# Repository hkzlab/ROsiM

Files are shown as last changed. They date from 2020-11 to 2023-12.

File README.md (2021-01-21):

# ROsiM - ROM simulator

## Introduction

The ROsiM is a ROM simulation / emulation board: it uses two 512k/8bit SRAM chips to simulate an 8 or 16 bit ROM (up to 512k bytes or 512k words in size).

The board is based around an ATMega328P chip @20Mhz, controlled via serial connection.

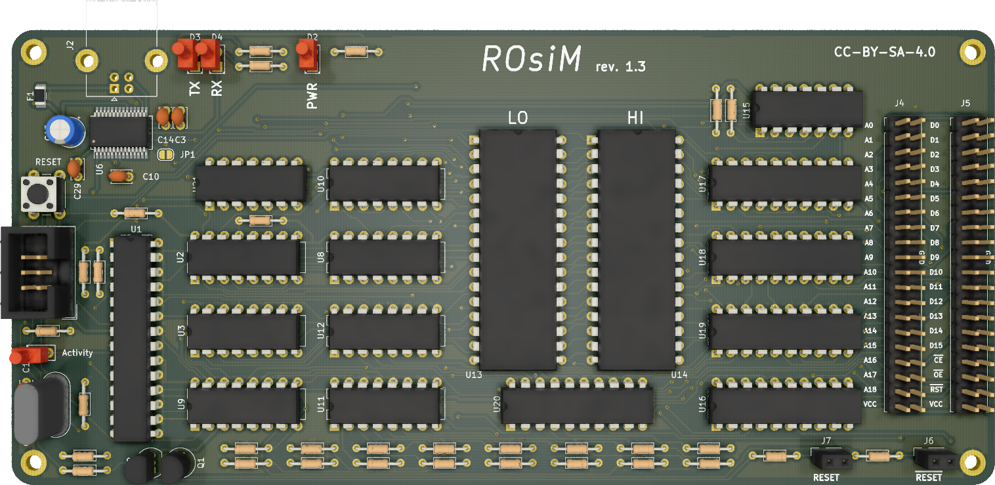
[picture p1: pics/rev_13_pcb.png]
Rev. 1.3 PCB


I made this out of my personal need of a simple way to quickly test ROM images on boards I repair/hack/build. Often, these boards use big 16bit EPROMs and the projects I found around did not cater to my needs.

The idea is to use this bare board and then "pods" that attach to the two 40pin header and adapt it to simulate various types of ROMs.

**WARNING:** While I might help you with quick questions, there is NOT going to be hand-holding for this one.

### Caveat Emptor!

I have currently built and tested revision 1.3 of this board. The following fixes must be implemented to make it usable:

- Wire the VCCIO pad from FT232RL to VCC and do NOT short it to 3.3v. This is already fixed in board rev. 1.4

The following mod is optional but encouraged for safety, and have been implemented for revision 1.4:

- Cut the trace between pin 1 of USB connector (Vcc) and F1, and insert a BAT48 SOD123 diode, cathode towards F1. This will protect your USB port if the board gets externally powered.
- Lower F1 max current to 200mA

## Board

This board is designed around relatively cheap through hole (with a few exceptions) components, and should be buildable by anyone with basic soldering skills.

You'll need a way to program your 328P MCU with the bootloader (you can then load the firmware via serial port).

I recommend [optiboot](https://github.com/Optiboot/optiboot). Remember to set the AVR frequency to 20Mhz and baudrate to 115200bps. I might provide prebuilt binaries of this in the future.

### Bill of Materials

**TODO**

### Connections

#### J1 - ISP 6 pin header

This is used for in-circuit programming of the MCU. You won't really use after burning the bootloader to the chip. You can leave this out if you pre-program the ATMega.

#### J2 - USB Type B female

Connect your USB cable here. It will appear as an FTDI serial port to the host.

The Interface runs at 230400bps 8-n-1. The protocol is mainly ASCII based, but meant to be used with an external software.

#### J3 - Barrel jack for power

Connect your DC power supply here, **center tip positive**.
Anything between 7 to 9V will be good, 12V will work, but the regulator might get hotter. 500mA should be enough.

#### J4 - Address header

A 40 pin header:

- Odd pins 1 thru 37 on the left side will bring out the address lines (A0-A18).
- Pin 39 will be this board's VCC.
- All even pins on the right are GND.

#### J5 - Data header

A 40 pin header: 

- Odd pins 1 thru 31 on the left side will bring out the data lines (D0-D15).
- Pin 33 will be the /CE signal input.
- Pin 35 will be the /OE signal input.
- Pin 39 will be this board's VCC.
- All even pins on the right are GND.

#### J6 - /RESET header

An active-low OC signal will be present on this header. You can use to pilot the /RESET of your target board.

Solder an arc of rigid wire on this one, so you can attach a small crocodile clip to it.

#### J7 - RESET header

An active-high signal (either high or disconnected) will be present on this header.

Solder an arc of rigid wire on this one, so you can attach a small crocodile clip to it.
## Software

While this board can be controlled directly via a simple serial terminal, it is advised to use a client software that supports the following protocol, like the [ROsiM Loader](https://github.com/hkzlab/ROsiM_Loader).

### Protocol

The **Remote Control** protocol is pretty simple and ASCII based. It supports 12 commands, each with its own syntax and response.

String `CMD_ERR` will be sent in case the command is not recognized, string `CMD_INV` will be sent in case the command cannot be executed at this time.

#### RESET

- Syntax: `>K<`
- Response: none

Forces the reset by watchdog of the ROsiM.

#### MODEL

- Syntax: `>M<`
- Response: `[M xx]`

Returns the current model of the board in hex. 

#### ADDRESS

- Syntax: `>A 00xxxxxx<`
- Response: `[A 00xxxxxx]`

Specifies the start address for the next read/write commands.
The address must be specified in hex, and a mask of 0x7FFFF will be applied to it.

#### WRITE

- Syntax: `>W xxxx<`
- Response: `[W xxxx]`

The SRAM must be in WRITE mode and the board switched to INTERNAL, otherwise the response `CMD_INV` will be sent.

`xxxx` is the data to write on SRAM at the current address in hex format.
Once the write completes, the **address will automatically increment by 1**.

#### READ

- Syntax: `>R<`
- Response: `[R xxxx]`

The SRAM must be in READ mode and the board switched to INTERNAL, otherwise the response `CMD_INV` will be sent.

`xxxx` is the data written at the current address in hex format. Once the read completes, the **address will automatically increment by 1**.

#### EXTERNAL RESET

- Syntax: `>E y<` where `y` can be `0` or `1`
- Response: `[E y]`

Enables (`1`) or disables (`0`) the external RESET signal to the target board.

#### INTERNAL/EXTERNAL SWITCH

- Syntax: `>S y<` where `y` can be `0` or `1`
- Response: `[S y]`

To execute this command, the SRAM must be in READ mode, otherwise the response `CMD_INV` will be sent.
Sets the board to INTERNAL (`1`) or EXTERNAL (`0`) mode. EXTERNAL mode will enable the drivers that communicate through the external address/data/control lines.

#### READ/WRITE SWITCH

- Syntax: `>X y<` where `y` can be `0` or `1`
- Response: `[X y]`

To execute this command, the board must be in INTERNAL mode, otherwise the response `CMD_INV` will be sent.
Sets the SRAM to READ (`1`) or WRITE (`0`) mode.

#### VIEW

- Syntax: `>V<`
- Response: `[V 00xxxxxx yy]`

This command will print out the current address in hex format (`00xxxxxx`) and a mask (`yy`) in hex format that contains:

- bit 0: INTERNAL/EXTERNAL state
- bit 1: READ/WRITE state
- bit 2: EXTERNAL RESET state

#### DEFAULTS

- Syntax: `>D<`
- Response: `[D]`

Will revert the board state to the following state:

- INTERNAL
- SRAM in READ mode
- EXTERNAL RESET disabled

The selection of the EXTERNAL RESET logic will **NOT** be restored by this command and will remain set to the current state.

#### TEST

- Syntax: `>T<`
- Response: `[T xx]`

Resets the board to defaults then executes a test on the SRAMs by writing patterns of data in them and reading them back.

The output can be:

- `00` test was completed successfully
- `01` test failed while writing the first pattern (`0xAA55`)
- `02` test failed while writing the first pattern (`0x55AA`)
- `03` the test failed while writing the incremental pattern

#### XMODEM

- Syntax: `>O x<`
- Response: `[O yy]`

Starts an XMODEM transfer of a binary file into the SRAM.

`x` can be:

- `0` The file will be considered an 8-bit dump, the highest 8 bits of the SRAM will be set to `0x00`, only the lower 8 bits will be set.
- `1` The file will be considered a 16-bit dump, and the data will be loaded into the SRAM in words. ODD bytes in the dump will end up in the high byte of the SRAM, EVEN bytes will end up in the low byte of the SRAM.
- `2` The file will be considered a **byte swapped** 16-bit dump, and the data will be loaded into the SRAM in words. EVEN bytes in the dump will end up in the high byte of the SRAM, ODD bytes will end up in the low byte of the SRAM.

`yy` will be:

- `00` for a failed transfer.
- `01` for a successful transfer.

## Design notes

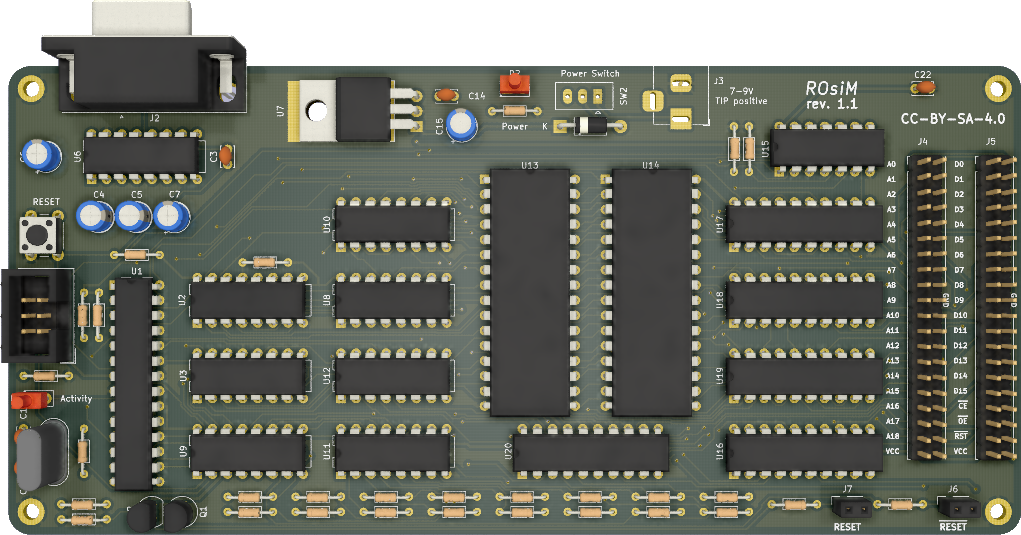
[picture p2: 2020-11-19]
pics/rev_11_pcb.png

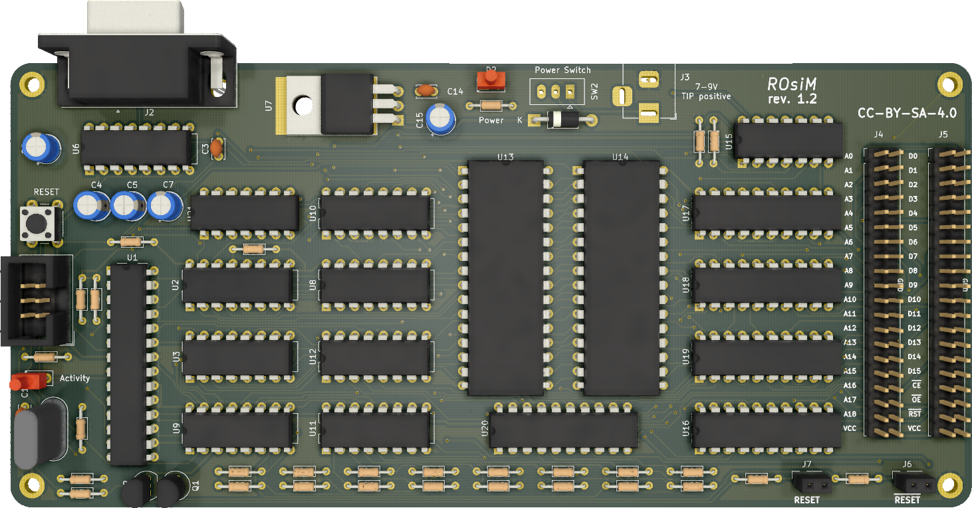
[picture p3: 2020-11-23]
pics/rev_12_pcb.png

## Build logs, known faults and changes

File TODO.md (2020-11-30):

## Use 1mbyte SRAMs

See if 1Mbyte SRAMs are available and use them for new designs.

## Use SPI for 'HC595

Use SPI to load HC595 registers instead of bit-banging them.

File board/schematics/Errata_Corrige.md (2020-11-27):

# Errata Corrige

## Version 1.1 - 1.3

- The MCU is actually an ATMega328P, not an ATMega8
- The crystal is a 20Mhz crystal, not 8Mhz

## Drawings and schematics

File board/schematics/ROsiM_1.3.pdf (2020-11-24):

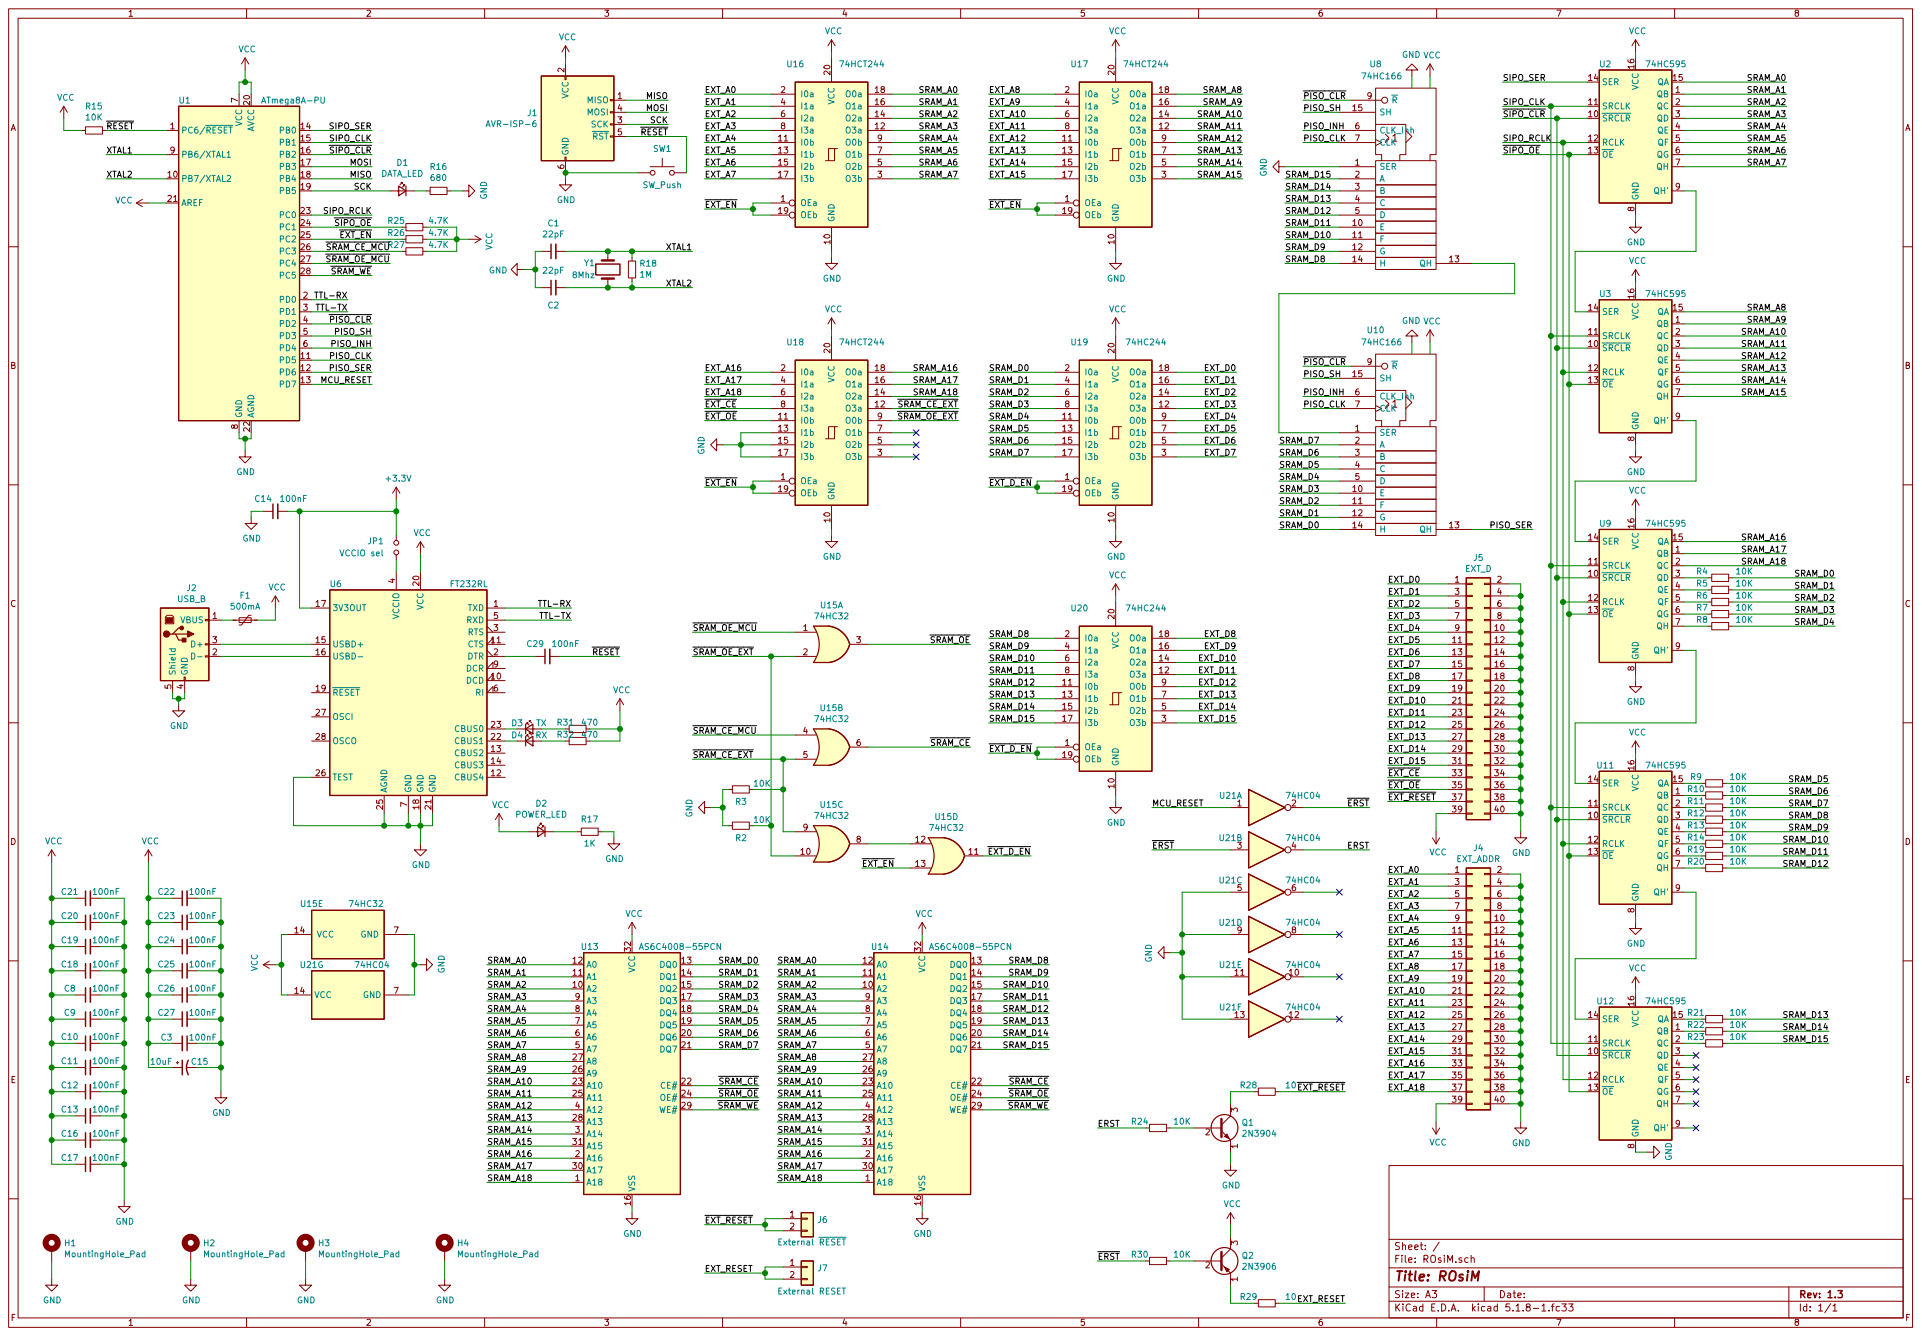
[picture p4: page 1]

2 SCK 3 MOSI 4 RST 5 GND

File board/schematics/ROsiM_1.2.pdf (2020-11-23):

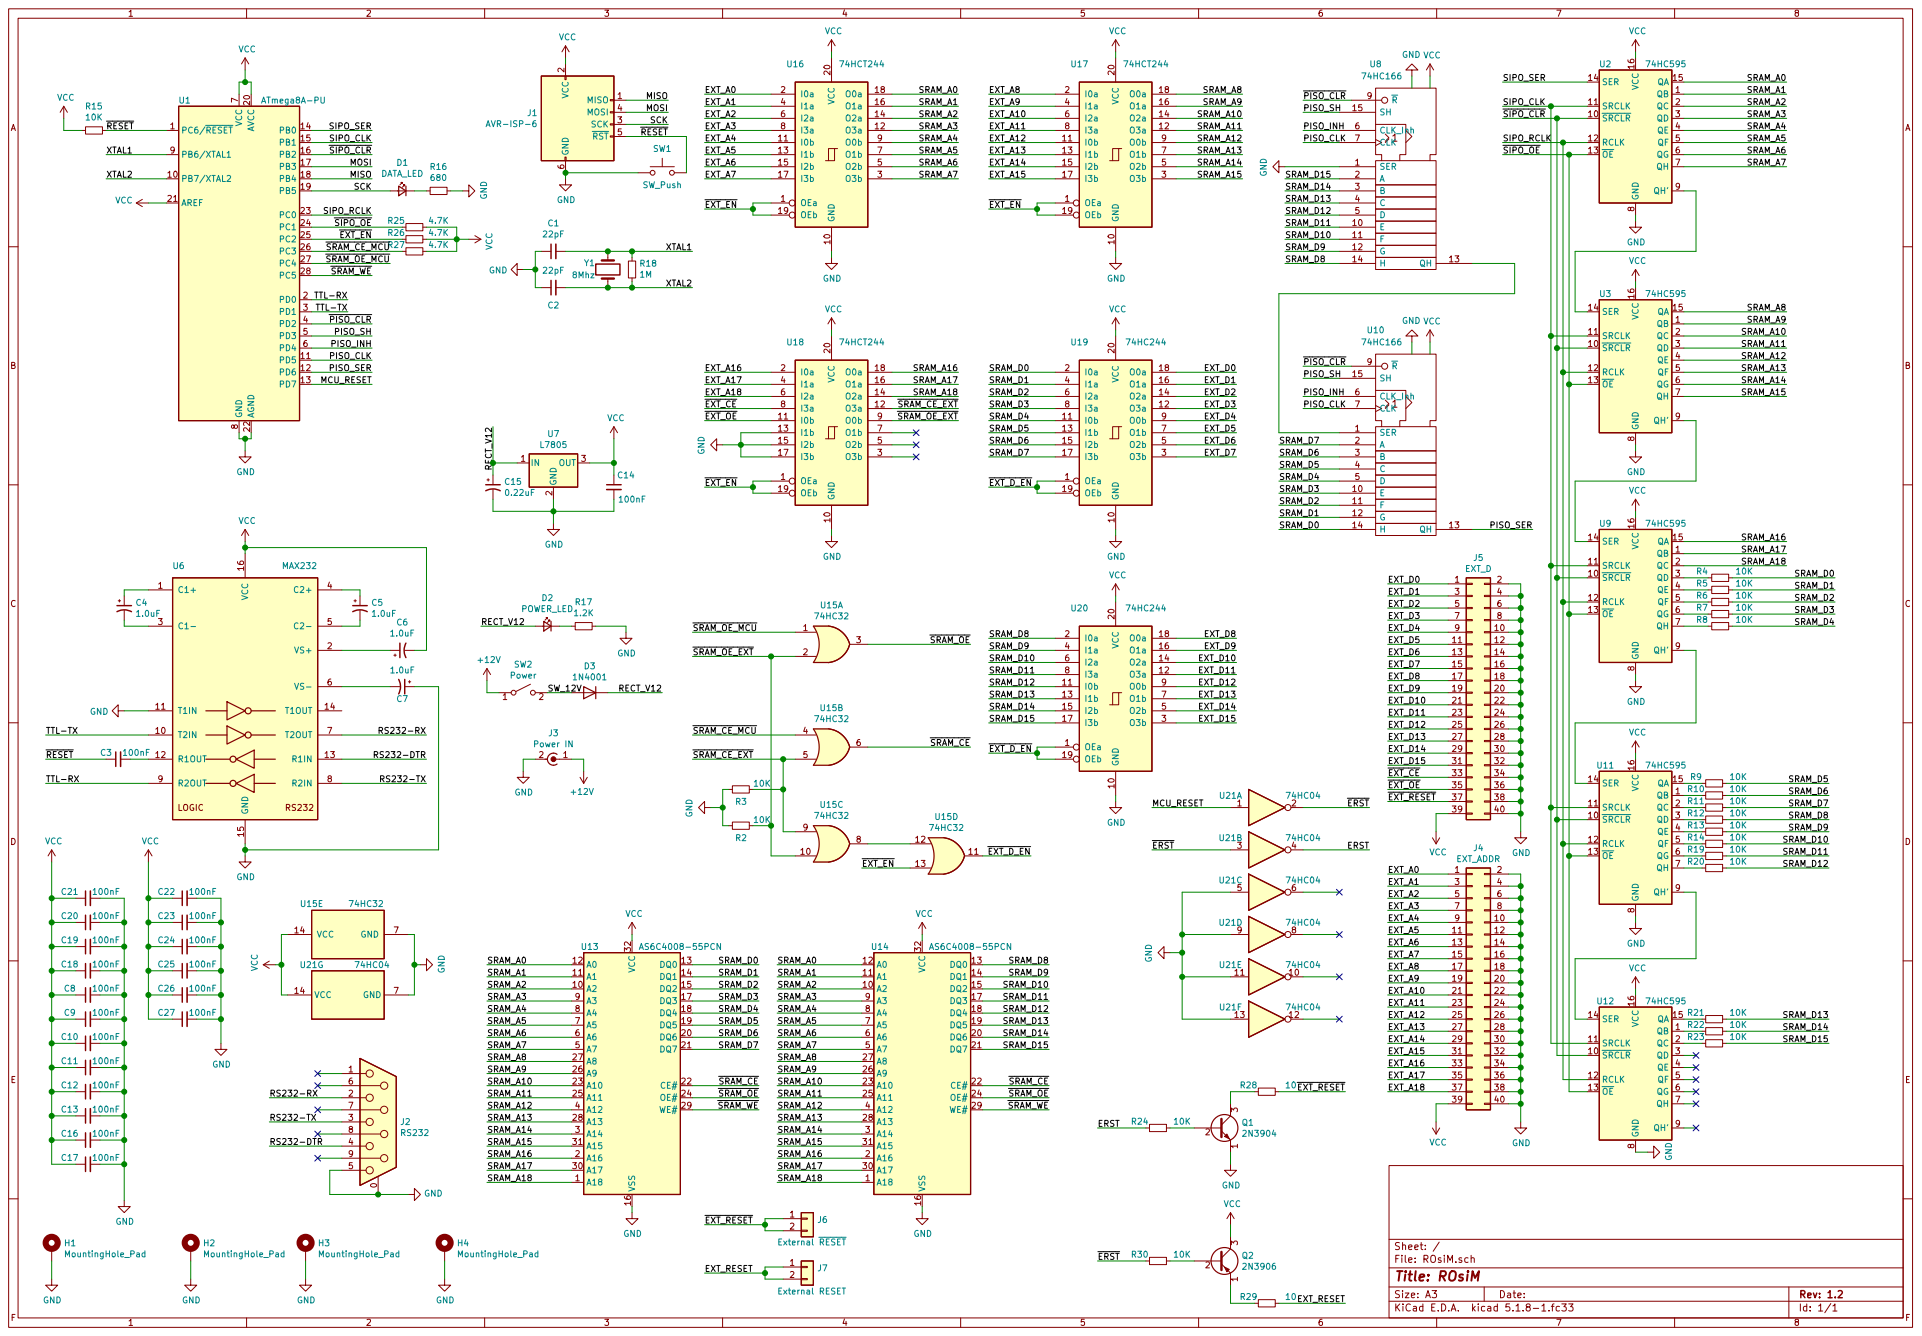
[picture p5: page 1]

2 SCK 3 MOSI 4 RST 5 GND

File: ROsiM.sch Sheet: /
Id: 1/1 Title: ROsiM

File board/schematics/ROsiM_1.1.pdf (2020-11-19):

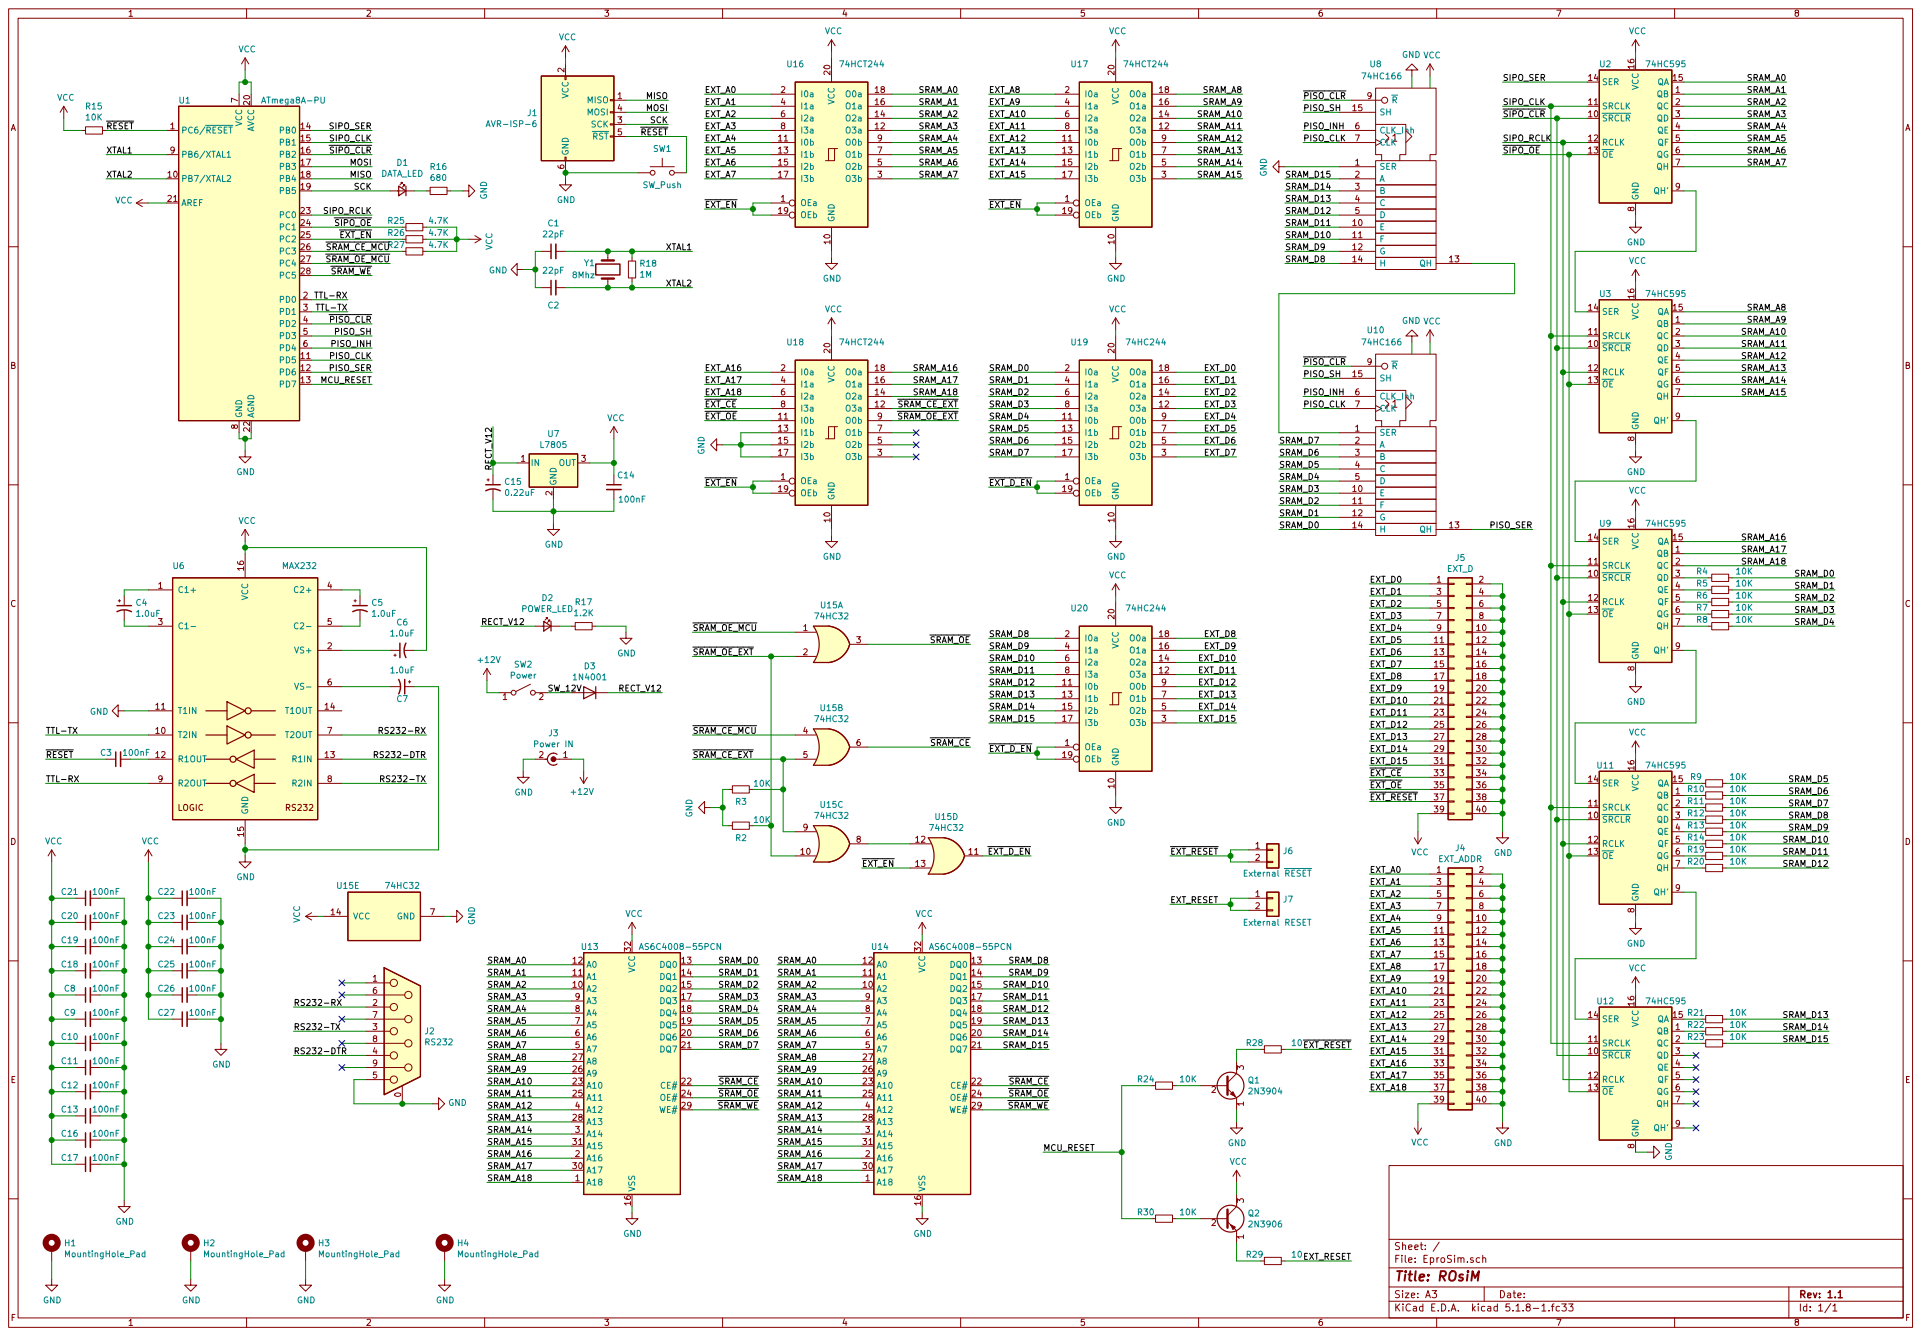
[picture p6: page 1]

2 SCK 3 MOSI 4 RST 5 GND

RESET SCK MOSI MISO

8 QH' 9 U9 74HC595 VCC GND GND

8 QH' 9 U12 74HC595 GND GND GND GND

File: EproSim.sch Sheet: /
Id: 1/1 Title: ROsiM

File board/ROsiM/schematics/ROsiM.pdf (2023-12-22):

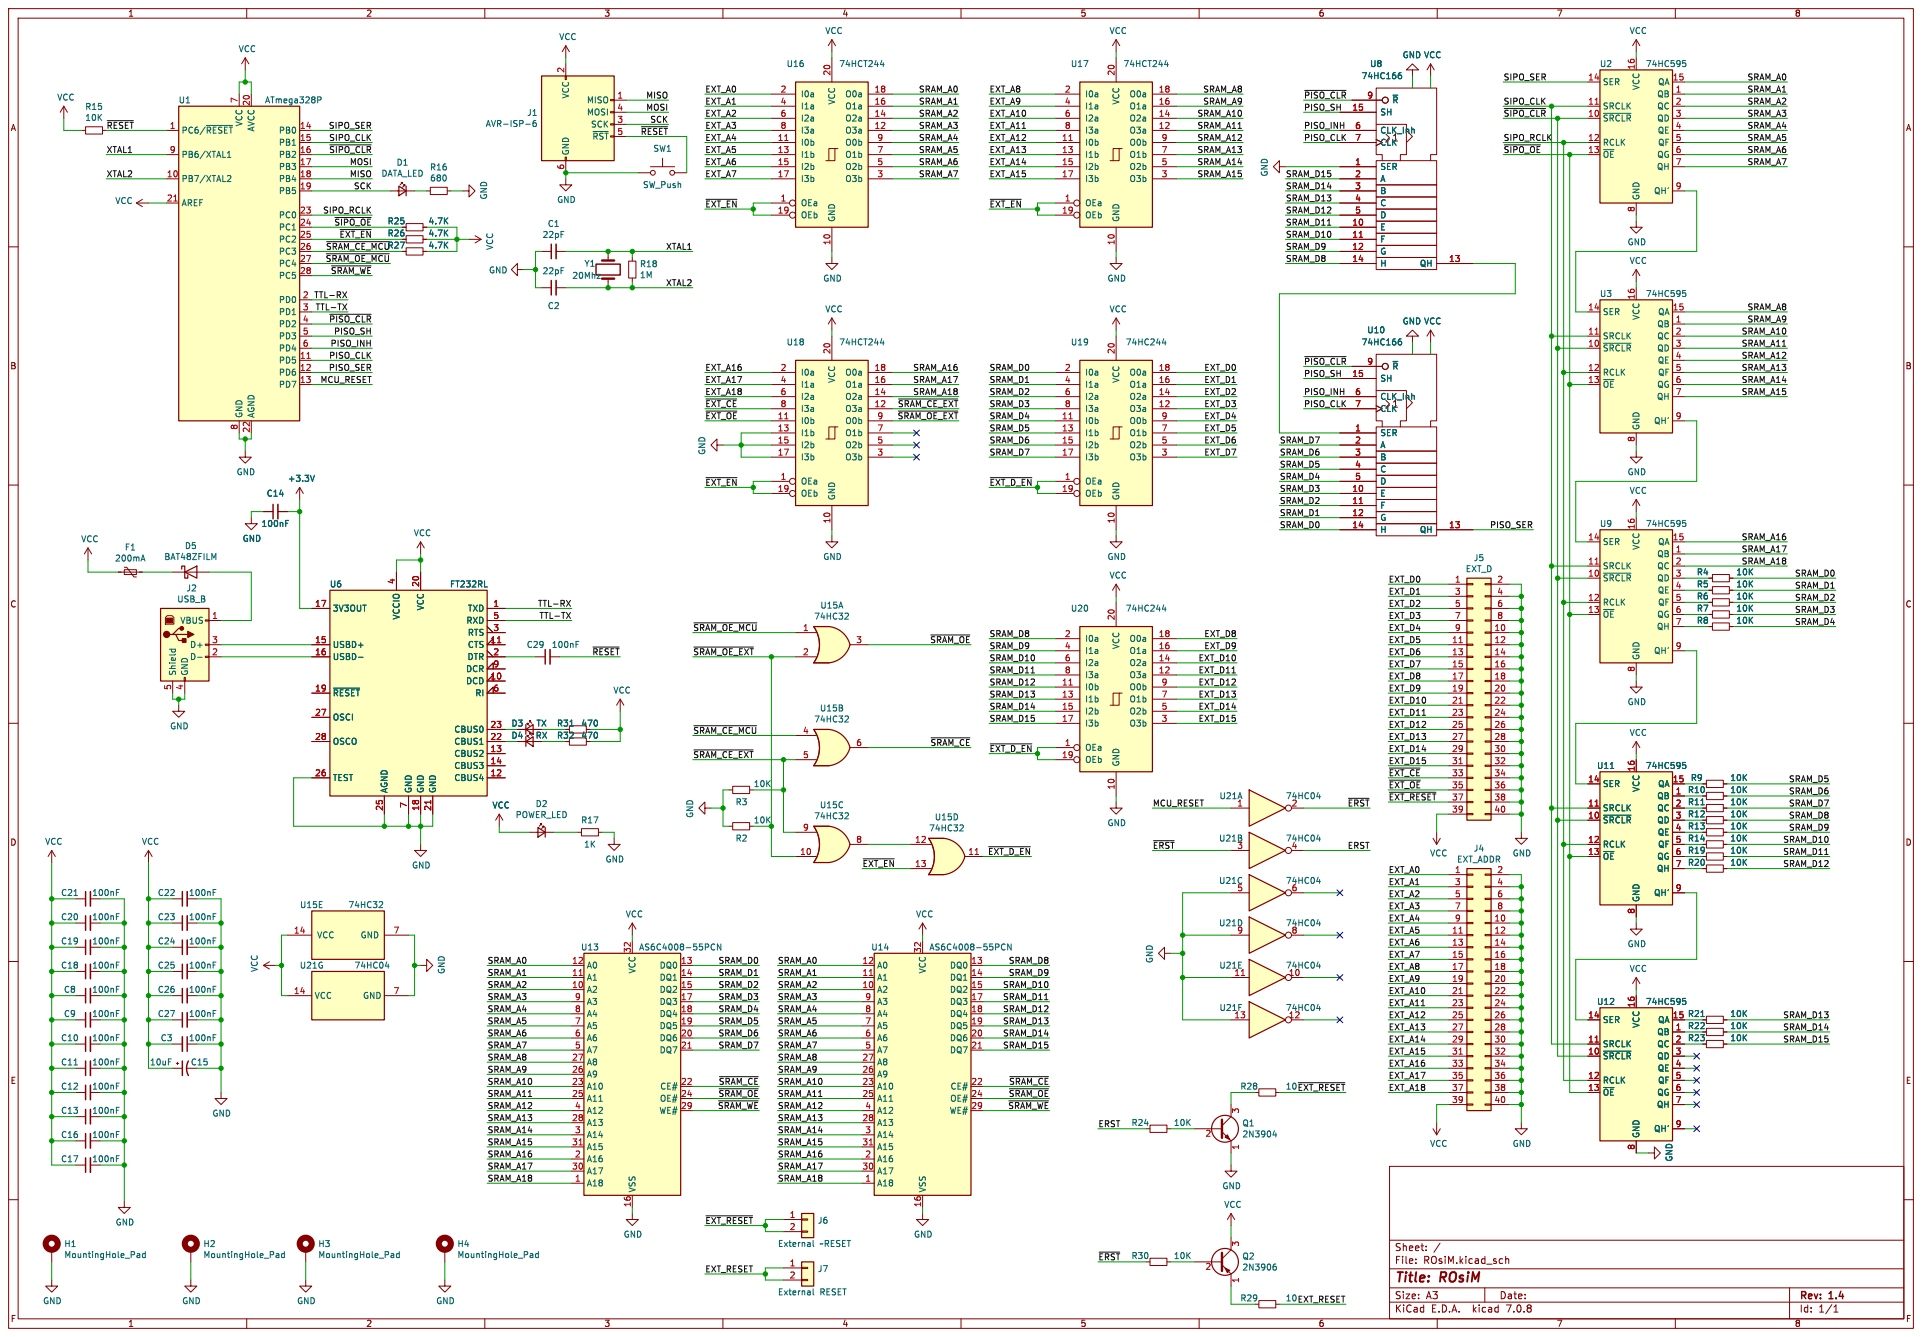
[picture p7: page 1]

7 DCR 9 GND VCC GND VCC

2 SCK 3 MOSI 4 ~{RST}5 GND
MISO VCC

SRAM_A3 MOSI SCK MOSI MISO

TXD 1 DCD 10 CTS 11 CBUS4 12 CBUS2 13 CBUS3 14 USBD+ 15 USBD- 16

7 DCR 9 U6 FT232RL VSS 16 VCC 32 A18 1 A2 10 A1 11 A0 12 DQ0 13 DQ1 14 DQ2 15 DQ3 17 DQ4 18 DQ5 19 A16 2 DQ6 20 DQ7 21 CE# 22 A10 23 OE# 24 A11 25 A9 26 A8 27 A13 28 WE# 29 A14 3 A17 30 A15 31 A12 4 A7 5 A6 6 A5 7 A4 8 A3 9 U13 AS6C4008-55PCN

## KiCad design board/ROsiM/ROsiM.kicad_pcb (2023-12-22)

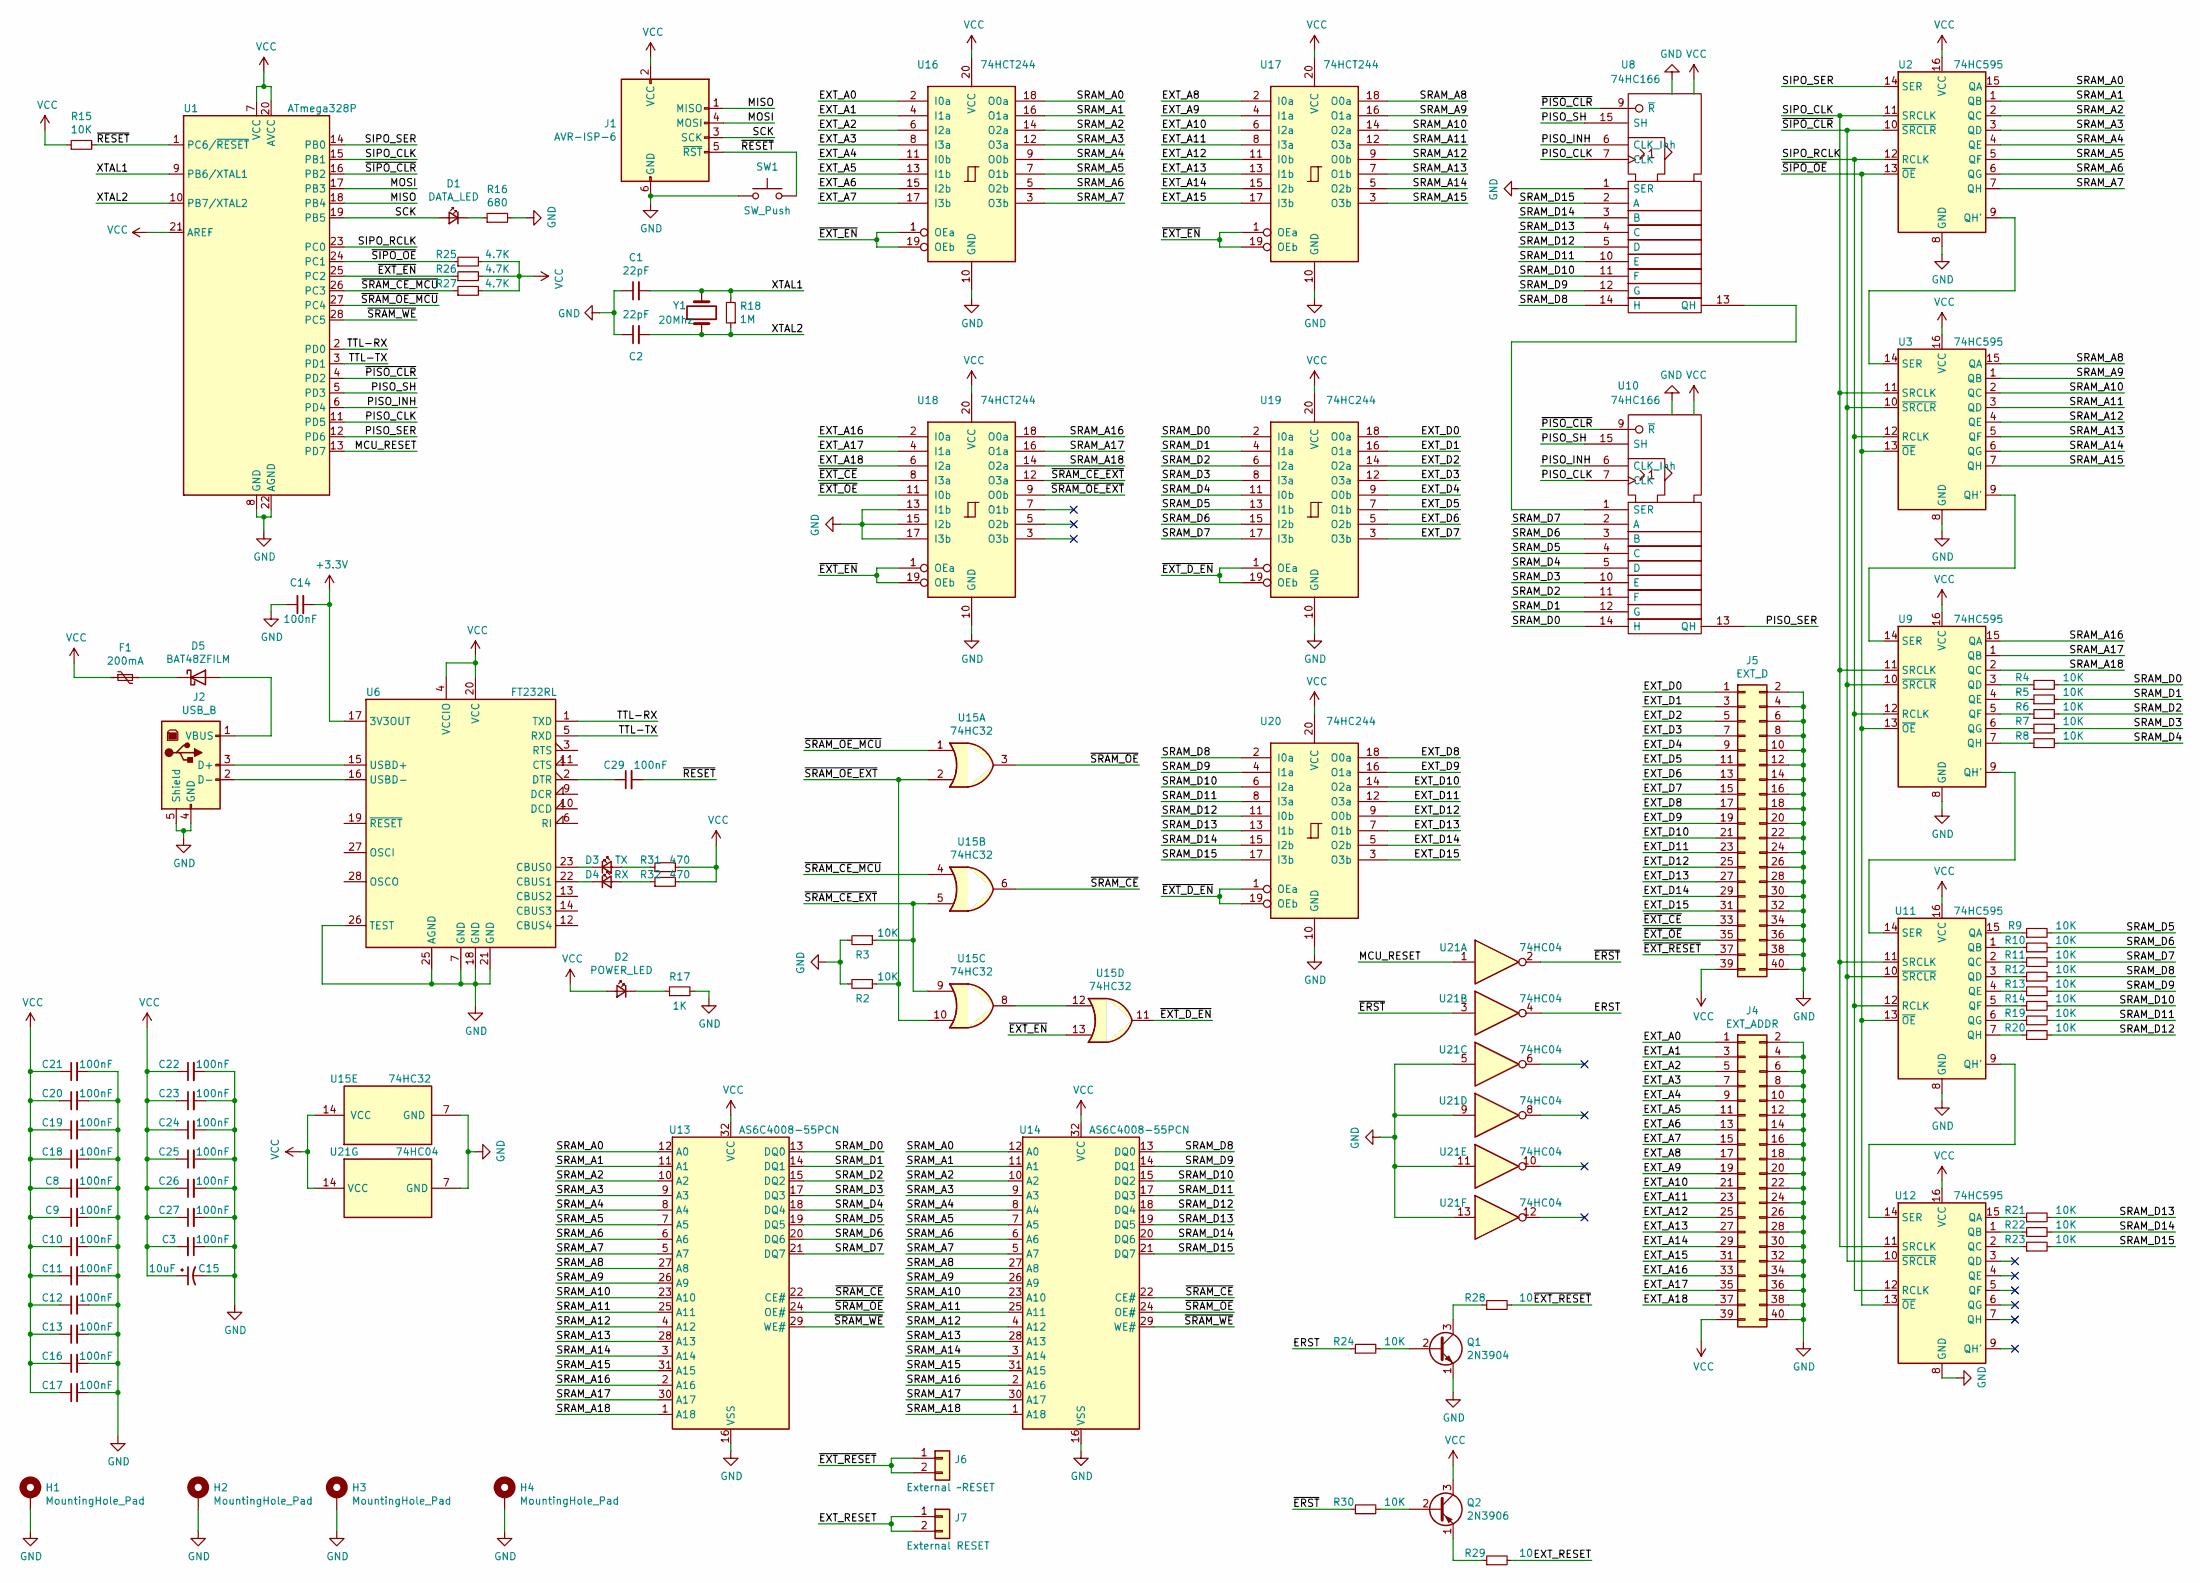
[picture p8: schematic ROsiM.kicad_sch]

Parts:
C1, C2: 22pF; C_Disc_D3.0mm_W2.0mm_P2.50mm
C3, C8, C9, C10, C11, C12, C13, C14, C16, C17, C18, C19, C20, C21, C22, C23, C24, C25, C26, C27, C29: 100nF; C_Disc_D3.4mm_W2.1mm_P2.50mm
C15: 10uF; CP_Radial_D5.0mm_P2.50mm
D1: DATA_LED; LED_D2.0mm_W4.8mm_H2.5mm_FlatTop
D2: POWER_LED; LED_D2.0mm_W4.8mm_H2.5mm_FlatTop
D3: TX; LED_D2.0mm_W4.8mm_H2.5mm_FlatTop
D4: RX; LED_D2.0mm_W4.8mm_H2.5mm_FlatTop
D5: BAT48ZFILM; D_SOD-123
F1: 200mA; Fuse_1206_3216Metric
H1, H2, H3, H4: MountingHole_Pad; MountingHole_2.7mm_M2.5_ISO7380_Pad
J1: AVR-ISP-6; IDC-Header_2x03_P2.54mm_Vertical
J2: USB_B; USB_B_Lumberg_2411_02_Horizontal
J4: EXT_ADDR; PinHeader_2x20_P2.54mm_Vertical
J5: EXT_D; PinHeader_2x20_P2.54mm_Vertical
J6: External ~RESET; PinSocket_1x02_P2.54mm_Vertical
J7: External RESET; PinSocket_1x02_P2.54mm_Vertical
Q1: 2N3904; TO-92_Inline
Q2: 2N3906; TO-92_Inline
R2, R3, R4, R5, R6, R7, R8, R9, R10, R11, R12, R13, R14, R15, R19, R20, R21, R22, R23, R24, R30: 10K; R_Axial_DIN0204_L3.6mm_D1.6mm_P7.62mm_Horizontal
R16: 680; R_Axial_DIN0204_L3.6mm_D1.6mm_P7.62mm_Horizontal
R17: 1K; R_Axial_DIN0204_L3.6mm_D1.6mm_P7.62mm_Horizontal
R18: 1M; R_Axial_DIN0204_L3.6mm_D1.6mm_P7.62mm_Horizontal
R25, R26, R27: 4.7K; R_Axial_DIN0204_L3.6mm_D1.6mm_P7.62mm_Horizontal
R28, R29: 10; R_Axial_DIN0204_L3.6mm_D1.6mm_P7.62mm_Horizontal
R31, R32: 470; R_Axial_DIN0204_L3.6mm_D1.6mm_P7.62mm_Horizontal
SW1: SW_Push; SW_PUSH_6mm
U1: ATmega328P; DIP-28_W7.62mm
U2, U3, U9, U11, U12: 74HC595; DIP-16_W7.62mm
U6: FT232RL; SSOP-28_5.3x10.2mm_P0.65mm
U8, U10: 74HC166; DIP-16_W7.62mm
U13, U14: AS6C4008-55PCN; DIP-32_W15.24mm
U15: 74HC32; DIP-14_W7.62mm
U16, U17, U18: 74HCT244; DIP-20_W7.62mm
U19, U20: 74HC244; DIP-20_W7.62mm
U21: 74HC04; DIP-14_W7.62mm
Y1: 20Mhz; Crystal_HC49-U_Vertical

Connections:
+3V3: C14.2, U6.17 (3V3OUT)
/ERST: R24.1, U21.4
/EXT_A0: J4.1, U16.2 (I0a)
/EXT_A1: J4.3, U16.4 (I1a)
/EXT_A2: J4.5, U16.6 (I2a)
/EXT_A3: J4.7, U16.8 (I3a)
/EXT_A4: J4.9, U16.11 (I0b)
/EXT_A5: J4.11, U16.13 (I1b)
/EXT_A6: J4.13, U16.15 (I2b)
/EXT_A7: J4.15, U16.17 (I3b)
/EXT_A8: J4.17, U17.2 (I0a)
/EXT_A9: J4.19, U17.4 (I1a)
/EXT_A10: J4.21, U17.6 (I2a)
/EXT_A11: J4.23, U17.8 (I3a)
/EXT_A12: J4.25, U17.11 (I0b)
/EXT_A13: J4.27, U17.13 (I1b)
/EXT_A14: J4.29, U17.15 (I2b)
/EXT_A15: J4.31, U17.17 (I3b)
/EXT_A16: J4.33, U18.2 (I0a)
/EXT_A17: J4.35, U18.4 (I1a)
/EXT_A18: J4.37, U18.6 (I2a)
/EXT_D0: J5.1, U19.18 (O0a)
/EXT_D1: J5.3, U19.16 (O1a)
/EXT_D2: J5.5, U19.14 (O2a)
/EXT_D3: J5.7, U19.12 (O3a)
/EXT_D4: J5.9, U19.9 (O0b)
/EXT_D5: J5.11, U19.7 (O1b)
/EXT_D6: J5.13, U19.5 (O2b)
/EXT_D7: J5.15, U19.3 (O3b)
/EXT_D8: J5.17, U20.18 (O0a)
/EXT_D9: J5.19, U20.16 (O1a)
/EXT_D10: J5.21, U20.14 (O2a)
/EXT_D11: J5.23, U20.12 (O3a)
/EXT_D12: J5.25, U20.9 (O0b)
/EXT_D13: J5.27, U20.7 (O1b)
/EXT_D14: J5.29, U20.5 (O2b)
/EXT_D15: J5.31, U20.3 (O3b)
/EXT_RESET: J7.1, J7.2, R29.2
/MCU_RESET: U1.13 (PD7), U21.1
/MISO: J1.1 (MISO), U1.18 (PB4)
/MOSI: J1.4 (MOSI), U1.17 (PB3)
/PISO_CLK: U1.11 (PD5), U8.7 (CLK), U10.7 (CLK)
/PISO_INH: U1.6 (PD4), U8.6 (CLK_Inh), U10.6 (CLK_Inh)
/PISO_SER: U1.12 (PD6), U10.13 (QH)
/PISO_SH: U1.5 (PD3), U8.15 (SH), U10.15 (SH)
/SCK: D1.2 (A), J1.3 (SCK), U1.19 (PB5)
/SIPO_CLK: U1.15 (PB1), U2.11 (SRCLK), U3.11 (SRCLK), U9.11 (SRCLK), U11.11 (SRCLK), U12.11 (SRCLK)
/SIPO_RCLK: U1.23 (PC0), U2.12 (RCLK), U3.12 (RCLK), U9.12 (RCLK), U11.12 (RCLK), U12.12 (RCLK)
/SIPO_SER: U1.14 (PB0), U2.14 (SER)
/SRAM_A0: U2.15 (QA), U13.12 (A0), U14.12 (A0), U16.18 (O0a)
/SRAM_A1: U2.1 (QB), U13.11 (A1), U14.11 (A1), U16.16 (O1a)
/SRAM_A2: U2.2 (QC), U13.10 (A2), U14.10 (A2), U16.14 (O2a)
/SRAM_A3: U2.3 (QD), U13.9 (A3), U14.9 (A3), U16.12 (O3a)
/SRAM_A4: U2.4 (QE), U13.8 (A4), U14.8 (A4), U16.9 (O0b)
/SRAM_A5: U2.5 (QF), U13.7 (A5), U14.7 (A5), U16.7 (O1b)
/SRAM_A6: U2.6 (QG), U13.6 (A6), U14.6 (A6), U16.5 (O2b)
/SRAM_A7: U2.7 (QH), U13.5 (A7), U14.5 (A7), U16.3 (O3b)
/SRAM_A8: U3.15 (QA), U13.27 (A8), U14.27 (A8), U17.18 (O0a)
/SRAM_A9: U3.1 (QB), U13.26 (A9), U14.26 (A9), U17.16 (O1a)
/SRAM_A10: U3.2 (QC), U13.23 (A10), U14.23 (A10), U17.14 (O2a)
/SRAM_A11: U3.3 (QD), U13.25 (A11), U14.25 (A11), U17.12 (O3a)
/SRAM_A12: U3.4 (QE), U13.4 (A12), U14.4 (A12), U17.9 (O0b)
/SRAM_A13: U3.5 (QF), U13.28 (A13), U14.28 (A13), U17.7 (O1b)
/SRAM_A14: U3.6 (QG), U13.3 (A14), U14.3 (A14), U17.5 (O2b)
/SRAM_A15: U3.7 (QH), U13.31 (A15), U14.31 (A15), U17.3 (O3b)
/SRAM_A16: U9.15 (QA), U13.2 (A16), U14.2 (A16), U18.18 (O0a)
/SRAM_A17: U9.1 (QB), U13.30 (A17), U14.30 (A17), U18.16 (O1a)
/SRAM_A18: U9.2 (QC), U13.1 (A18), U14.1 (A18), U18.14 (O2a)
/SRAM_D0: R4.2, U10.14 (H), U13.13 (DQ0), U19.2 (I0a)
/SRAM_D1: R5.2, U10.12 (G), U13.14 (DQ1), U19.4 (I1a)
/SRAM_D2: R6.2, U10.11 (F), U13.15 (DQ2), U19.6 (I2a)
/SRAM_D3: R7.2, U10.10 (E), U13.17 (DQ3), U19.8 (I3a)
/SRAM_D4: R8.2, U10.5 (D), U13.18 (DQ4), U19.11 (I0b)
/SRAM_D5: R9.2, U10.4 (C), U13.19 (DQ5), U19.13 (I1b)
/SRAM_D6: R10.2, U10.3 (B), U13.20 (DQ6), U19.15 (I2b)
/SRAM_D7: R11.2, U10.2 (A), U13.21 (DQ7), U19.17 (I3b)
/SRAM_D8: R12.2, U8.14 (H), U14.13 (DQ0), U20.2 (I0a)
/SRAM_D9: R13.2, U8.12 (G), U14.14 (DQ1), U20.4 (I1a)
/SRAM_D10: R14.2, U8.11 (F), U14.15 (DQ2), U20.6 (I2a)
/SRAM_D11: R19.2, U8.10 (E), U14.17 (DQ3), U20.8 (I3a)
/SRAM_D12: R20.2, U8.5 (D), U14.18 (DQ4), U20.11 (I0b)
/SRAM_D13: R21.2, U8.4 (C), U14.19 (DQ5), U20.13 (I1b)
/SRAM_D14: R22.2, U8.3 (B), U14.20 (DQ6), U20.15 (I2b)
/SRAM_D15: R23.2, U8.2 (A), U14.21 (DQ7), U20.17 (I3b)
/TTL-RX: U1.2 (PD0), U6.1 (TXD)
/TTL-TX: U1.3 (PD1), U6.5 (RXD)
/XTAL1: C1.2, R18.2, U1.9 (PB6/XTAL1), Y1.2
/XTAL2: C2.2, R18.1, U1.10 (PB7/XTAL2), Y1.1
/~ERST: R30.1, U21.2, U21.3
/~EXT_CE: J5.33, U18.8 (I3a)
/~EXT_D_EN: U15.11, U19.1 (OEa), U19.19 (OEb), U20.1 (OEa), U20.19 (OEb)
/~EXT_EN: R26.1, U1.25 (PC2), U15.13, U16.1 (OEa), U16.19 (OEb), U17.1 (OEa), U17.19 (OEb), U18.1 (OEa), U18.19 (OEb)
/~EXT_OE: J5.35, U18.11 (I0b)
/~EXT_RESET: J5.37, J6.1, J6.2, R28.2
/~PISO_CLR: U1.4 (PD2), U8.9 (~R), U10.9 (~R)
/~RESET: C29.2, J1.5 (~RST), R15.2, SW1.2, U1.1 (PC6/~RESET)
/~SIPO_CLR: U1.16 (PB2), U2.10 (~SRCLR), U3.10 (~SRCLR), U9.10 (~SRCLR), U11.10 (~SRCLR), U12.10 (~SRCLR)
/~SIPO_OE: R25.1, U1.24 (PC1), U2.13 (~OE), U3.13 (~OE), U9.13 (~OE), U11.13 (~OE), U12.13 (~OE)
/~SRAM_CE_EXT: R3.1, U15.5, U15.9, U18.12 (O3a)
/~SRAM_CE_MCU: R27.1, U1.26 (PC3), U15.4
/~SRAM_CE: U13.22 (CE#), U14.22 (CE#), U15.6
/~SRAM_OE_EXT: R2.1, U15.2, U15.10, U18.9 (O0b)
/~SRAM_OE_MCU: U1.27 (PC4), U15.1
/~SRAM_OE: U13.24 (OE#), U14.24 (OE#), U15.3
/~SRAM_WE: U1.28 (PC5), U13.29 (WE#), U14.29 (WE#)
GND: C1.1, C2.1, C3.1, C8.2, C9.2, C10.2, C11.2, C12.2, C13.2, C14.1, C15.2, C16.2, C17.2, C18.2, C19.2, C20.2, C21.2, C22.2, C23.2, C24.2, C25.2, C26.2, C27.2, H1.1, H2.1, H3.1, H4.1, J1.6 (GND), J2.4 (GND), J2.5 (Shield), J4.2, J4.4, J4.6, J4.8, J4.10, J4.12, J4.14, J4.16, J4.18, J4.20, J4.22, J4.24, J4.26, J4.28, J4.30, J4.32, J4.34, J4.36, J4.38, J4.40, J5.2, J5.4, J5.6, J5.8, J5.10, J5.12, J5.14, J5.16, J5.18, J5.20, J5.22, J5.24, J5.26, J5.28, J5.30, J5.32, J5.34, J5.36, J5.38, J5.40, Q1.1 (E), R2.2, R3.2, R16.2, R17.2, SW1.1, U1.8 (GND), U1.22 (AGND), U2.8 (GND), U3.8 (GND), U6.7 (GND), U6.18 (GND), U6.21 (GND), U6.25 (AGND), U6.26 (TEST), U8.1 (SER), U8.8 (GND), U9.8 (GND), U10.8 (GND), U11.8 (GND), U12.8 (GND), U13.16 (VSS), U14.16 (VSS), U15.7 (GND), U16.10 (GND), U17.10 (GND), U18.10 (GND), U18.13 (I1b), U18.15 (I2b), U18.17 (I3b), U19.10 (GND), U20.10 (GND), U21.5, U21.7 (GND), U21.9, U21.11, U21.13
unnamed: C29.1, U6.2 (DTR)
unnamed: D1.1 (K), R16.1
unnamed: D2.1 (K), R17.1
unnamed: D3.1 (K), U6.23 (CBUS0)
unnamed: D3.2 (A), R31.1
unnamed: D4.1 (K), U6.22 (CBUS1)
unnamed: D4.2 (A), R32.1
unnamed: D5.1 (K), F1.2
unnamed: D5.2 (A), J2.1 (VBUS)
unnamed: J2.2 (D-), U6.16 (USBD-)
unnamed: J2.3 (D+), U6.15 (USBD+)
unnamed: Q1.2 (B), R24.2
unnamed: Q1.3 (C), R28.1
unnamed: Q2.1 (E), R29.1
unnamed: Q2.2 (B), R30.2
unnamed: R4.1, U9.3 (QD)
unnamed: R5.1, U9.4 (QE)
unnamed: R6.1, U9.5 (QF)
unnamed: R7.1, U9.6 (QG)
unnamed: R8.1, U9.7 (QH)
unnamed: R9.1, U11.15 (QA)
unnamed: R10.1, U11.1 (QB)
unnamed: R11.1, U11.2 (QC)
unnamed: R12.1, U11.3 (QD)
unnamed: R13.1, U11.4 (QE)
unnamed: R14.1, U11.5 (QF)
unnamed: R19.1, U11.6 (QG)
unnamed: R20.1, U11.7 (QH)
unnamed: R21.1, U12.15 (QA)
unnamed: R22.1, U12.1 (QB)
unnamed: R23.1, U12.2 (QC)
unnamed: U2.9 (QH'), U3.14 (SER)
unnamed: U3.9 (QH'), U9.14 (SER)
unnamed: U8.13 (QH), U10.1 (SER)
unnamed: U11.9 (QH'), U12.14 (SER)
unnamed: U9.9 (QH'), U11.14 (SER)
unnamed: U15.8, U15.12
VCC: C3.2, C8.1, C9.1, C10.1, C11.1, C12.1, C13.1, C15.1, C16.1, C17.1, C18.1, C19.1, C20.1, C21.1, C22.1, C23.1, C24.1, C25.1, C26.1, C27.1, D2.2 (A), F1.1, J1.2 (VCC), J4.39, J5.39, Q2.3 (C), R15.1, R25.2, R26.2, R27.2, R31.2, R32.2, U1.7 (VCC), U1.20 (AVCC), U1.21 (AREF), U2.16 (VCC), U3.16 (VCC), U6.4 (VCCIO), U6.20 (VCC), U8.16 (VCC), U9.16 (VCC), U10.16 (VCC), U11.16 (VCC), U12.16 (VCC), U13.32 (VCC), U14.32 (VCC), U15.14 (VCC), U16.20 (VCC), U17.20 (VCC), U18.20 (VCC), U19.20 (VCC), U20.20 (VCC), U21.14 (VCC)

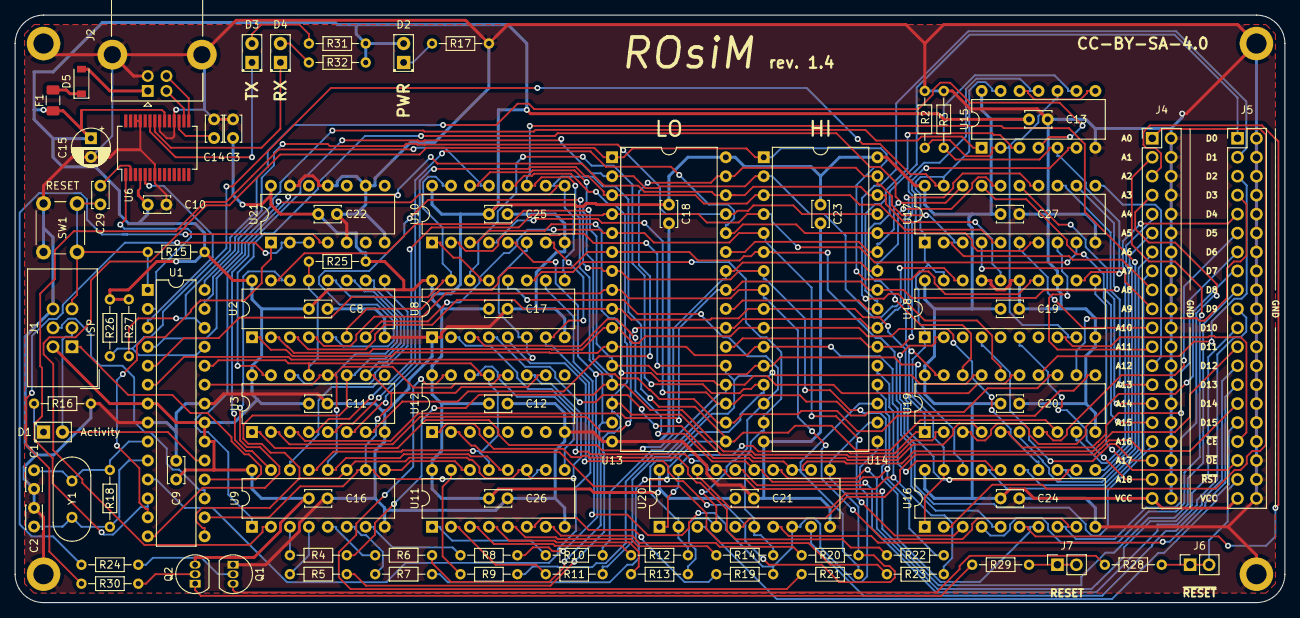
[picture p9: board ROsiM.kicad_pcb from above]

Board: 2 copper layers, 170.2 x 78.7 mm, 93 parts (0 on the bottom side), 144 nets.

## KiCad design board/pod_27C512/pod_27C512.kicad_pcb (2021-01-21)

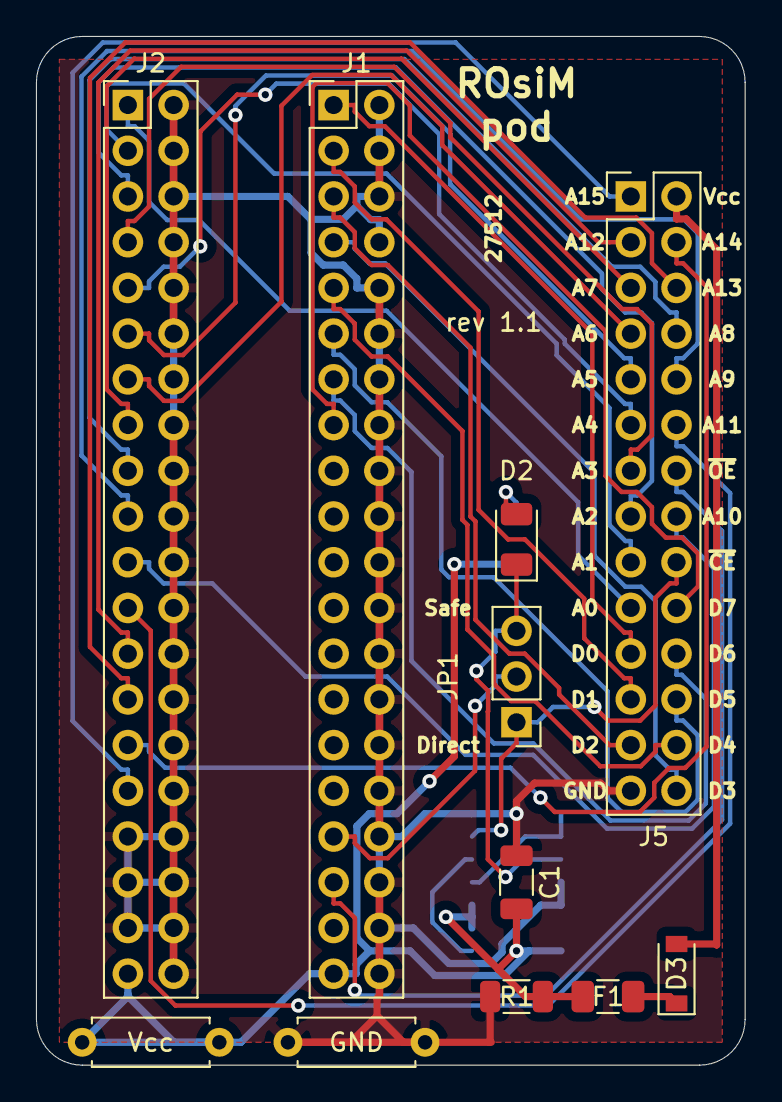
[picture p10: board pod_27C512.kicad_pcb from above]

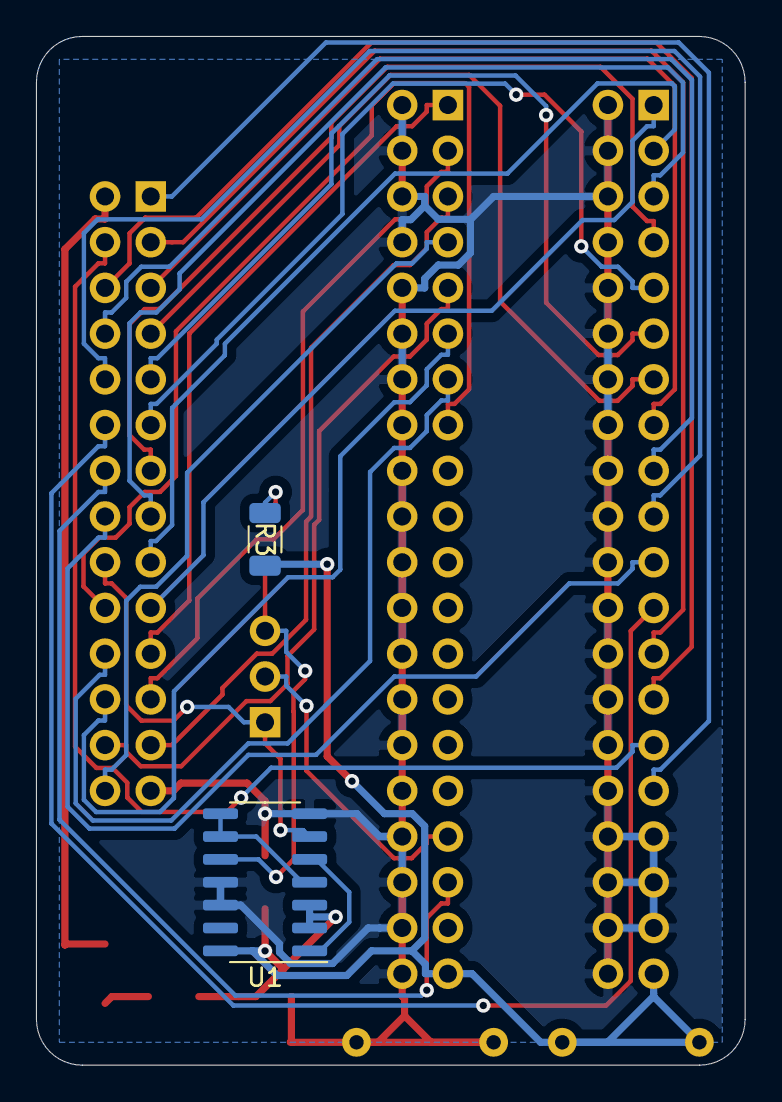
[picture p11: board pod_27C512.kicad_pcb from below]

Board: 2 copper layers, 39.4 x 57.2 mm, 13 parts (2 on the bottom side), 35 nets.

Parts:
C1: 100nF; C_1206_3216Metric
D2: GREEN; LED_1206_3216Metric
D3: BAT48ZFILM; D_SOD-123
F1: 200mA; Fuse_1206_3216Metric
J1: EXT_D; PinHeader_2x20_P2.54mm_Vertical
J2: EXT_ADDR; PinHeader_2x20_P2.54mm_Vertical
J3: VCC_Probe; R_Axial_DIN0207_L6.3mm_D2.5mm_P7.62mm_Horizontal
J4: GND_Probe; R_Axial_DIN0207_L6.3mm_D2.5mm_P7.62mm_Horizontal
J5: ROM Lines; PinHeader_2x14_P2.54mm_Vertical
JP1: /OE Selection; PinHeader_1x03_P2.54mm_Vertical
R1: 4.7K; R_1206_3216Metric
R3: 470; R_1206_3216Metric
U1: 74HCT02; SO-14_3.9x8.65mm_P1.27mm

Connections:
/A0: J2.1, J5.19
/A1: J2.3, J5.17
/A2: J2.5, J5.15
/A3: J2.7, J5.13
/A4: J2.9, J5.11
/A5: J2.11, J5.9
/A6: J2.13, J5.7
/A7: J2.15, J5.5
/A8: J2.17, J5.8
/A9: J2.19, J5.10
/A10: J2.21, J5.16
/A11: J2.23, J5.12
/A12: J2.25, J5.3
/A13: J2.27, J5.6
/A14: J2.29, J5.4
/A15: J2.31, J5.1
/D0: J1.1, J5.21
/D1: J1.3, J5.23
/D2: J1.5, J5.25
/D3: J1.7, J5.28
/D4: J1.9, J5.26
/D5: J1.11, J5.24
/D6: J1.13, J5.22
/D7: J1.15, J5.20
/~B_CE: J1.33, JP1.2
/~DIR_CE: J5.18, JP1.1, U1.6
/~OE: J1.35, J5.14
/~SAFE_CE: D2.1, JP1.3, U1.10
GND: C1.1, J1.2, J1.4, J1.6, J1.8, J1.10, J1.12, J1.14, J1.16, J1.18, J1.20, J1.22, J1.24, J1.26, J1.28, J1.30, J1.32, J1.34, J1.36, J1.38, J1.40, J2.2, J2.4, J2.6, J2.8, J2.10, J2.12, J2.14, J2.16, J2.18, J2.20, J2.22, J2.24, J2.26, J2.28, J2.30, J2.32, J2.33, J2.34, J2.35, J2.36, J2.37, J2.38, J2.40, J4.1, J4.2, J5.27, R1.1, U1.7, U1.11, U1.12
unnamed: D2.2, R3.1
unnamed: D3.1, F1.1
unnamed: D3.2, J5.2
unnamed: U1.1, U1.5
unnamed: U1.4, U1.8, U1.9
VCC: C1.2, F1.2, J1.39, J2.39, J3.1, J3.2, R1.2, R3.2, U1.2, U1.3, U1.14

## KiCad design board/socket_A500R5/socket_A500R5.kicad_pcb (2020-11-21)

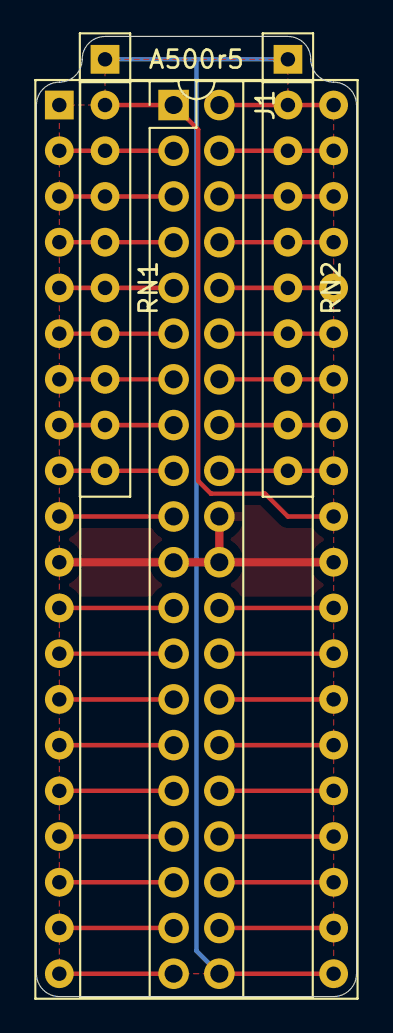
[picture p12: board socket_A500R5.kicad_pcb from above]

Board: 2 copper layers, 17.8 x 53.3 mm, 4 parts (0 on the bottom side), 38 nets.

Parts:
A500r5: A500 R5; DIP-40_W15.24mm_Socket
J1: Adapter; PinHeader_2x20_P2.54mm_Vertical
RN1, RN2: 4k7; R_Array_SIP10

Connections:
/A0: A500r5.9, J1.17, RN1.10
/A1: A500r5.8, J1.15, RN1.9
/A2: A500r5.7, J1.13, RN1.8
/A3: A500r5.6, J1.11, RN1.7
/A4: A500r5.5, J1.9, RN1.6
/A5: A500r5.4, J1.7, RN1.5
/A6: A500r5.3, J1.5, RN1.4
/A7: A500r5.2, J1.3, RN1.3
/A8: A500r5.40, J1.2, RN2.2
/A9: A500r5.39, J1.4, RN2.3
/A10: A500r5.38, J1.6, RN2.4
/A11: A500r5.37, J1.8, RN2.5
/A12: A500r5.36, J1.10, RN2.6
/A13: A500r5.35, J1.12, RN2.7
/A14: A500r5.34, J1.14, RN2.8
/A15: A500r5.33, J1.16, RN2.9
/A16: A500r5.32, J1.18, RN2.10
/A17: A500r5.31, J1.1, RN1.2
/D0: A500r5.13, J1.25
/D1: A500r5.15, J1.29
/D2: A500r5.17, J1.33
/D3: A500r5.19, J1.37
/D4: A500r5.22, J1.38
/D5: A500r5.24, J1.34
/D6: A500r5.26, J1.30
/D7: A500r5.28, J1.26
/D8: A500r5.14, J1.27
/D9: A500r5.16, J1.31
/D10: A500r5.18, J1.35
/D11: A500r5.20, J1.39
/D12: A500r5.23, J1.36
/D13: A500r5.25, J1.32
/D14: A500r5.27, J1.28
/D15: A500r5.29, J1.24
/EXT_VCC: A500r5.21, J1.40, RN1.1, RN2.1
/~CE: A500r5.10, J1.19
/~OE: A500r5.12, J1.23
GND: A500r5.11, A500r5.30, J1.20, J1.21, J1.22

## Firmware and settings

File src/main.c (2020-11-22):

#include "main.h"

#include <stdint.h>
#include <stdlib.h>

#include <avr/io.h>
#include <avr/wdt.h>
#include <avr/interrupt.h>

#include <util/delay.h>

#include <interface/remote_control.h>

#include <ioutils/mcu_io.h>
#include <ioutils/ioutils.h>

#include <utils/millis.h>

#include <uart/uart.h> 
#include <shifter/sipo_shifter.h>
#include <shifter/piso_shifter.h>


#define VERSION "0.0.3"
#define SOFT_HEADER "\nROsiM - " VERSION "\n\n"

int main(void) {
#if defined (__AVR_ATmega328P__)
    wdt_enable(WDTO_4S); // Enable the watchdog to reset in 4 seconds...
#elif defined (__AVR_ATmega8A__)
    wdt_enable(WDTO_2S); // Enable the watchdog to reset in 2 seconds...
#endif

    // Initialize the I/O and communications
    io_init();

    // First watchdog kick
    wdt_reset();

    // Initialize serial port
    uart_init();
    
    // Prepare the shifters
    sipo_shifter_init();
    piso_shifter_init();
    
    // Initialize the millisecond library
    millis_init();

    // Enable interrupts
    sei();

    uart_puts(SOFT_HEADER); // Print the header

    ioutils_setLED(0); // Turn off the activity LED

    remote_control();

    uart_puts("DONE.\n");

    // We're done, blink the led at 1Hz and wait for a watchdog reset
    while(1) {
        _delay_ms(1000);
        ioutils_setLED(0);
        _delay_ms(1000);
    }


    return 0;
}

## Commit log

2020-10-28 Basic files
    [EproSim.sch]
2020-10-28 Add caps
    [EproSim.sch]
2020-10-28 Add resistors to SIPO shifter for data out
    [EproSim.sch]
2020-10-28 Add external reset code
    [EproSim.sch]
2020-10-28 Fix multiple D3
    [EproSim.sch]
2020-10-28 Add external connector
    [EproSim.sch]
2020-10-28 Add some footprints
    [EproSim.sch]
2020-10-28 Make sure the Dout xcvers are disabled when the ROM is not selected
    [EproSim.sch]
2020-10-28 Add resistor on the reset line
    [EproSim.sch]
2020-10-28 Add transistor for OC reset output
    [EproSim.sch]
2020-10-28 Move around some components
    [EproSim.sch]
2020-10-28 Begin drawing the PCB
    [EproSim.kicad_pcb]
2020-10-29 Begin organizing ROsiM board
    [EproSim.kicad_pcb]
2020-10-29 Begin routing traces
    [EproSim.kicad_pcb]
2020-10-29 Complete routing
    [EproSim.kicad_pcb]
2020-10-29 Update PCB
    [EproSim.kicad_pcb]
2020-10-29 Fix solder mask issue
    [EproSim.kicad_pcb]
2020-10-30 Add pull-up to disable drivers and shifters
    [EproSim.sch]
2020-10-30 Added another resitor for SRAM CE
    [EproSim.sch]
2020-10-30 Add resistors to pullup sram selection
    [EproSim.kicad_pcb]
2020-11-13 Removed other unused pin initializations
2020-11-14 Fix string print for VIEW command
2020-11-14 More changes on the switch between external and internal
2020-11-15 Optimize test code print a bit
2020-11-17 Add pod and update TODO
    [pod_27C512.kicad_pcb, pod_27C512.sch]
2020-11-17 Update first pod schematics
    [pod_27C512.sch]
2020-11-17 Update pod project
    [pod_27C512.kicad_pcb, pod_27C512.sch]
2020-11-18 Add delays during IO switch to make sure there are no conflicts
2020-11-18 Make sure WE is not enabled if switching board from int to ext
2020-11-19 Add socket for 27C512
    [socket_27C512.kicad_pcb, socket_27C512.sch]
2020-11-19 Rev 1.1 of the board, and initial readme
    [EproSim.kicad_pcb, EproSim.sch]
2020-11-19 Added board PDF
    [EproSim.sch]
2020-11-19 Begin wiring up the xfer table
2020-11-20 Added gerbers for rev 1.1
2020-11-21 Add 27C256 socket
    [socket_27C256.kicad_pcb, socket_27C256.sch]
2020-11-21 Add sockets for 27C32 and 64
    [socket_27C32.kicad_pcb, socket_27C32.sch, socket_27C64.kicad_pcb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]
2020-11-21 Add 2716 socket
    [socket_27C16.kicad_pcb, socket_27C16.sch]
2020-11-21 Add pod for 27040
    [pod_27C040.kicad_pcb, pod_27C040.sch]
2020-11-21 Added pod for 27C400, modified other pods
    [pod_27C040.kicad_pcb, pod_27C400.kicad_pcb, pod_27C400.sch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]
2020-11-21 Add 27C400/16 socket
    [socket_27C16.kicad_pcb, socket_27C256.kicad_pcb, socket_27C32.kicad_pcb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]
2020-11-21 Add 27C400 / 8 bit mode socket
    [socket_27C400B.kicad_pcb, socket_27C400B.sch]
2020-11-21 Add socket for 27C020 and 27C040
    [socket_27C020.kicad_pcb, socket_27C020.sch, socket_27C040.kicad_pcb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]
2020-11-21 Added a500 socket
    [socket_29C040.kicad_pcb, socket_29C040.sch, socket_A500R5.kicad_pcb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]
2020-11-22 Force the board in a safe state when we're forcing a reset
2020-11-22 Force unused address lines to low for 27C512 pod
    [pod_27C512.kicad_pcb, pod_27C512.sch]
2020-11-22 Add code to invert reset logic, uniform reset parameter with the rest
    [main.c]
2020-11-23 Renamed ROsiM board
    [ROsiM.kicad_pcb, ROsiM.sch]
2020-11-23 Updating for 1.2 PCB
    [ROsiM.kicad_pcb, ROsiM.sch]
2020-11-24 Begin designing rev 1.3
    [ROsiM.kicad_pcb, ROsiM.sch]
2020-11-24 Updated readme and 1.3 pcb
    [ROsiM.kicad_pcb, ROsiM.sch]
2020-11-24 Whoops, a cap was inverted
    [ROsiM.kicad_pcb, ROsiM.sch]
2020-11-27 Update the schematics
    [ROsiM.sch]
2020-11-27 Add gerbers for boards
    [pod_27C512.kicad_pcb]
2020-12-12 Update the 27C512 pod by adding a protection diode
    [pod_27C512.kicad_pcb, pod_27C512.sch]
2020-12-12 Update all the pods to include the diode
    [pod_27C040.kicad_pcb, pod_27C040.sch, pod_27C400.kicad_pcb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]
2020-12-13 Update ROsiM design
    [ROsiM.kicad_pcb, ROsiM.sch]
2021-01-21 Added schottky diode on USB +5v input
    [ROsiM.kicad_pcb, ROsiM.sch]
2021-01-21 Lower specification of F1 to 200mA, to stay under BAT48 max current
    [ROsiM.kicad_pcb, ROsiM.sch]
2021-01-21 Update 27C040 pod
    [pod_27C040.kicad_pcb, pod_27C040.sch]
2021-01-21 Update 27C400 Pod
    [pod_27C400.kicad_pcb, pod_27C400.sch]
2021-01-21 Update 27C512 pod
    [pod_27C040.sch, pod_27C512.kicad_pcb, pod_27C512.sch]
2021-11-09 Update KiCad URL
2023-12-22 Update part of the project for kicad 7
    [ROsiM.kicad_pcb, ROsiM.kicad_sch, ROsiM.sch]

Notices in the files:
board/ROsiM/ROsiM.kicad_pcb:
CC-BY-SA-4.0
